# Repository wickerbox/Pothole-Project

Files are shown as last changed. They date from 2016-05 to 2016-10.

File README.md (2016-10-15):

# Pothole Project
Developing a low-cost device to collect and report real-time road information for cities. 

#### Step 1

Arduino 101 Shield using Fona, OBD-II/CAN circuitry, and an SD card. The board schematic was designed but not reviewed; the board was never laid out. 

Next step: lay out the board in KiCad and assemble a prototype

#### Step 2 

Standalone board using Fona, Curie chip, OBD-II/CAN circuitry, and an SD card. Ideally, it would fit into port so it could be left there to just do its thing.

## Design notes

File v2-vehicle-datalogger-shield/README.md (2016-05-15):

# Pothole Project
## Vehicle Datalogger Shield v1.0 

This shield is heavily based on the OBDII-UART adapter board from Sparkfun and ScanTool, but it adds headers for the Fona 808 2G + GPS breakout board and CC3000 Wifi breakout board, and provides an onboard miniSD holder for datalogging.  

### Bill of Materials

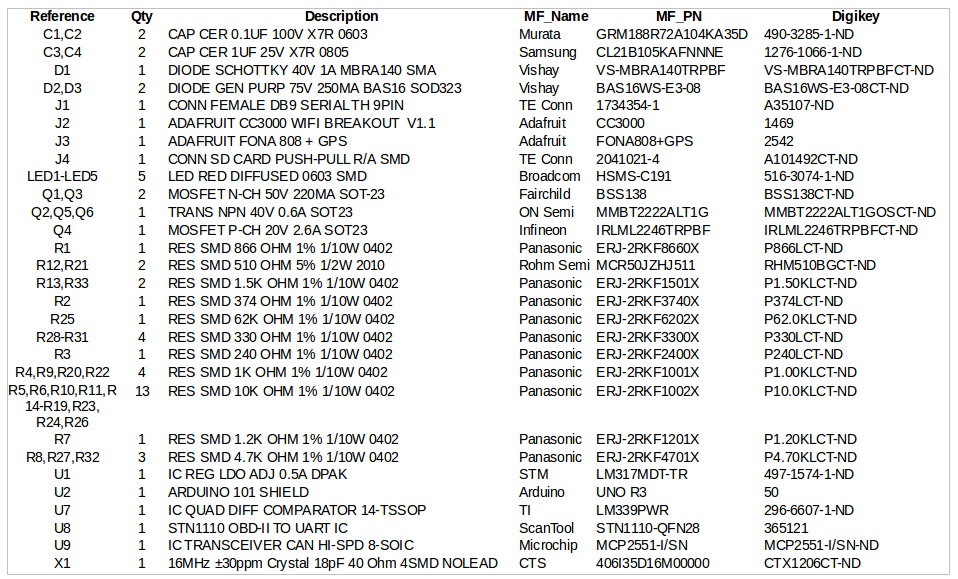
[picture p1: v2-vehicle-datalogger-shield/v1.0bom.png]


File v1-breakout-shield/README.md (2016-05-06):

# Pothole Project
## Hardware v1.0 

This is a simple breakout board to attach an OBDII-UART adapter board, Fona 808 2G + GPS breakout board, and an SD card to the Arduino 101. 

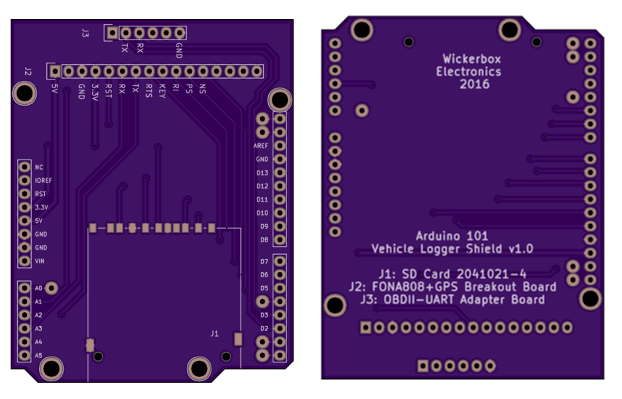
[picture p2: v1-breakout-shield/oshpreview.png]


### Bill of Materials

|Part|Source|Link|
|----|---|----|
|Arduino 101|Adafruit|<a href="https://www.adafruit.com/products/3033">$39.95</a>|
|Fona 808 2G + GPS Breakout Board|Adafruit|<a href="https://www.adafruit.com/products/2542">$49.95</a>|
|OBDII-UART Adapter Board|Sparkfun|<a href="https://www.sparkfun.com/products/9555">$49.95</a>
|SD Card holder|Digikey|<a href="http://www.digikey.com/product-search/en?keywords=A101492CT-ND">$3.10</a>|
|1x06 0.1" pitch female header|Digikey|<a href="http://www.digikey.com/product-search/en?keywords=952-1808-ND">$0.97</a>|
|1x16 0.1" pitch female header|Digikey|<a href="http://www.digikey.com/product-detail/en/sullins-connector-solutions/PPPC161LFBN-RC/S7049-ND/810188">$1.27</a>|

The printed board is a 2 layer board of 2.71x2.11 inches (69x53mm). $28.45 for three.

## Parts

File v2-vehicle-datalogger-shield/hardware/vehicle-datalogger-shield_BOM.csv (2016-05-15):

'Reference' | 'Qty' | 'Description' | 'MF_Name' | 'MF_PN' | 'Digikey'
'C1 | C2' | '2' | 'CAP CER 0.1UF 100V X7R 0603' | 'Murata' | 'GRM188R72A104KA35D' | '490-3285-1-ND'
'C3 | C4' | '2' | 'CAP CER 1UF 25V X7R 0805' | 'Samsung' | 'CL21B105KAFNNNE' | '1276-1066-1-ND'
'D1' | '1' | 'DIODE SCHOTTKY 40V 1A MBRA140 SMA' | 'Vishay' | 'VS-MBRA140TRPBF' | 'VS-MBRA140TRPBFCT-ND'
'D2 | D3' | '2' | 'DIODE GEN PURP 75V 250MA BAS16 SOD323' | 'Vishay' | 'BAS16WS-E3-08' | 'BAS16WS-E3-08CT-ND'
'J1' | '1' | 'CONN FEMALE DB9 SERIAL TH 9PIN' | 'TE Conn' | '1734354-1' | 'A35107-ND'
'J2' | '1' | 'ADAFRUIT CC3000 WIFI BREAKOUT V1.1' | 'Adafruit' | 'CC3000' | '1469'
'J3' | '1' | 'ADAFRUIT FONA 808 + GPS' | 'Adafruit' | 'FONA808+GPS' | '2542'
'J4' | '1' | 'CONN SD CARD PUSH-PULL R/A SMD' | 'TE Conn' | '2041021-4' | 'A101492CT-ND'
'LED1-LED5' | '5' | 'LED RED DIFFUSED 0603 SMD' | 'Broadcom' | 'HSMS-C191' | '516-3074-1-ND'
'Q1 | Q3' | '2' | 'MOSFET N-CH 50V 220MA SOT-23' | 'Fairchild' | 'BSS138' | 'BSS138CT-ND'
'Q2 | Q5 | Q6' | '1' | 'TRANS NPN 40V 0.6A SOT23' | 'ON Semi' | 'MMBT2222ALT1G' | 'MMBT2222ALT1GOSCT-ND'
'Q4' | '1' | 'MOSFET P-CH 20V 2.6A SOT23' | 'Infineon' | 'IRLML2246TRPBF' | 'IRLML2246TRPBFCT-ND'
'R1' | '1' | 'RES SMD 866 OHM 1% 1/10W 0402' | 'Panasonic' | 'ERJ-2RKF8660X' | 'P866LCT-ND'
'R12 | R21' | '2' | 'RES SMD 510 OHM 5% 1/2W 2010' | 'Rohm Semi' | 'MCR50JZHJ511' | 'RHM510BGCT-ND'
'R13 | R33' | '2' | 'RES SMD 1.5K OHM 1% 1/10W 0402' | 'Panasonic' | 'ERJ-2RKF1501X' | 'P1.50KLCT-ND'
'R2' | '1' | 'RES SMD 374 OHM 1% 1/10W 0402' | 'Panasonic' | 'ERJ-2RKF3740X' | 'P374LCT-ND'
'R25' | '1' | 'RES SMD 62K OHM 1% 1/10W 0402' | 'Panasonic' | 'ERJ-2RKF6202X' | 'P62.0KLCT-ND'
'R28-R31' | '4' | 'RES SMD 330 OHM 1% 1/10W 0402' | 'Panasonic' | 'ERJ-2RKF3300X' | 'P330LCT-ND'
'R3' | '1' | 'RES SMD 240 OHM 1% 1/10W 0402' | 'Panasonic' | 'ERJ-2RKF2400X' | 'P240LCT-ND'
'R4 | R9 | R20 | R22' | '4' | 'RES SMD 1K OHM 1% 1/10W 0402' | 'Panasonic' | 'ERJ-2RKF1001X' | 'P1.00KLCT-ND'
'R5 | R6 | R10 | R11 | R14-R19 | R23 | R24 | R26' | '13' | 'RES SMD 10K OHM 1% 1/10W 0402' | 'Panasonic' | 'ERJ-2RKF1002X' | 'P10.0KLCT-ND'
'R7' | '1' | 'RES SMD 1.2K OHM 1% 1/10W 0402' | 'Panasonic' | 'ERJ-2RKF1201X' | 'P1.20KLCT-ND'
'R8 | R27 | R32' | '3' | 'RES SMD 4.7K OHM 1% 1/10W 0402' | 'Panasonic' | 'ERJ-2RKF4701X' | 'P4.70KLCT-ND'
'U1' | '1' | 'IC REG LDO ADJ 0.5A DPAK' | 'STM' | 'LM317MDT-TR' | '497-1574-1-ND'
'U2' | '1' | 'ARDUINO 101 SHIELD' | 'Arduino' | 'UNO R3' | '50'
'U7' | '1' | 'IC QUAD DIFF COMPARATOR 14-TSSOP' | 'TI' | 'LM339PWR' | '296-6607-1-ND'
'U8' | '1' | 'STN1110 OBD-II TO UART IC' | 'ScanTool' | 'STN1110-QFN28' | '365121'
'U9' | '1' | 'IC TRANSCEIVER CAN HI-SPD 8-SOIC' | 'Microchip' | 'MCP2551-I/SN' | 'MCP2551-I/SN-ND'
'X1' | '1' | '16MHz ±30ppm Crystal 18pF 40 Ohm 4SMD NOLEAD' | 'CTS' | '406I35D16M00000' | 'CTX1206CT-ND'

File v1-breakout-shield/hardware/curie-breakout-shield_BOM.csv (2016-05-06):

Reference | Value | Footprint | Count | Datasheet | Package | MF_Name | MF_PN | S1_Name | S1_PN | Description | Verified
U1;U2;U3;U4 | HOLE | Wickerlib:ARDUINO-MOUNTING-HOLE | 4 | https://www.adafruit.com/products/50 | ARDU-101SHIELD | Arduino | 101 | Adafruit | 50 | ARDUINO 101 | Not Verified
U5 | ARDUINO-101-SHIELD | Wickerlib:ARDUINO-101-SHIELD | 1 | https://www.adafruit.com/products/3033 | ARDU-101SHIELD | Arduino | UNO R3 | Adafruit | 50 | ARDUINO 101 SHIELD | Not Verified
J1 | CONN-SD-CARD-PUSH-PULL-R/A-SMD | Wickerlib:SD_Holder_FullSize | 1 | http://www.te.com/commerce/DocumentDelivery/DDEController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 | SD_Holder_FullSize | TE Conn | 2041021-4 | Digikey | A101492CT-ND | CONN SD CARD PUSH-PULL R/A SMD | Not Verified
J2 | FONA808-GPS | Wickerlib:Pin_Header_Straight_1x16 | 1 | https://www.adafruit.com/products/2542 | FONA808-GPS | Adafruit | FONA808+GPS | Adafruit | 2542 | ADAFRUIT FONA 808 + GPS | Not Verified
J3 | OBDII-UART | Wickerlib:Pin_Header_Straight_1x06 | 1 | https://cdn.harwin.com/pdfs/60page140.pdf | Pin_Header_Straight_1x06 | Harwin | M20-7820642 | Digikey | 952-1808-ND | HEADER FEMALE 6POS TH 1x06 0.1” | Not Verified
W2 | A0 | Wickerlib:TestHole_1x01 | 1
W4 | A4 | Wickerlib:TestHole_1x01 | 1
W6 | A5 | Wickerlib:TestHole_1x01 | 1
W1 | D0 | Wickerlib:TestHole_1x01 | 1
W3 | D1 | Wickerlib:TestHole_1x01 | 1
W5 | D4 | Wickerlib:TestHole_1x01 | 1

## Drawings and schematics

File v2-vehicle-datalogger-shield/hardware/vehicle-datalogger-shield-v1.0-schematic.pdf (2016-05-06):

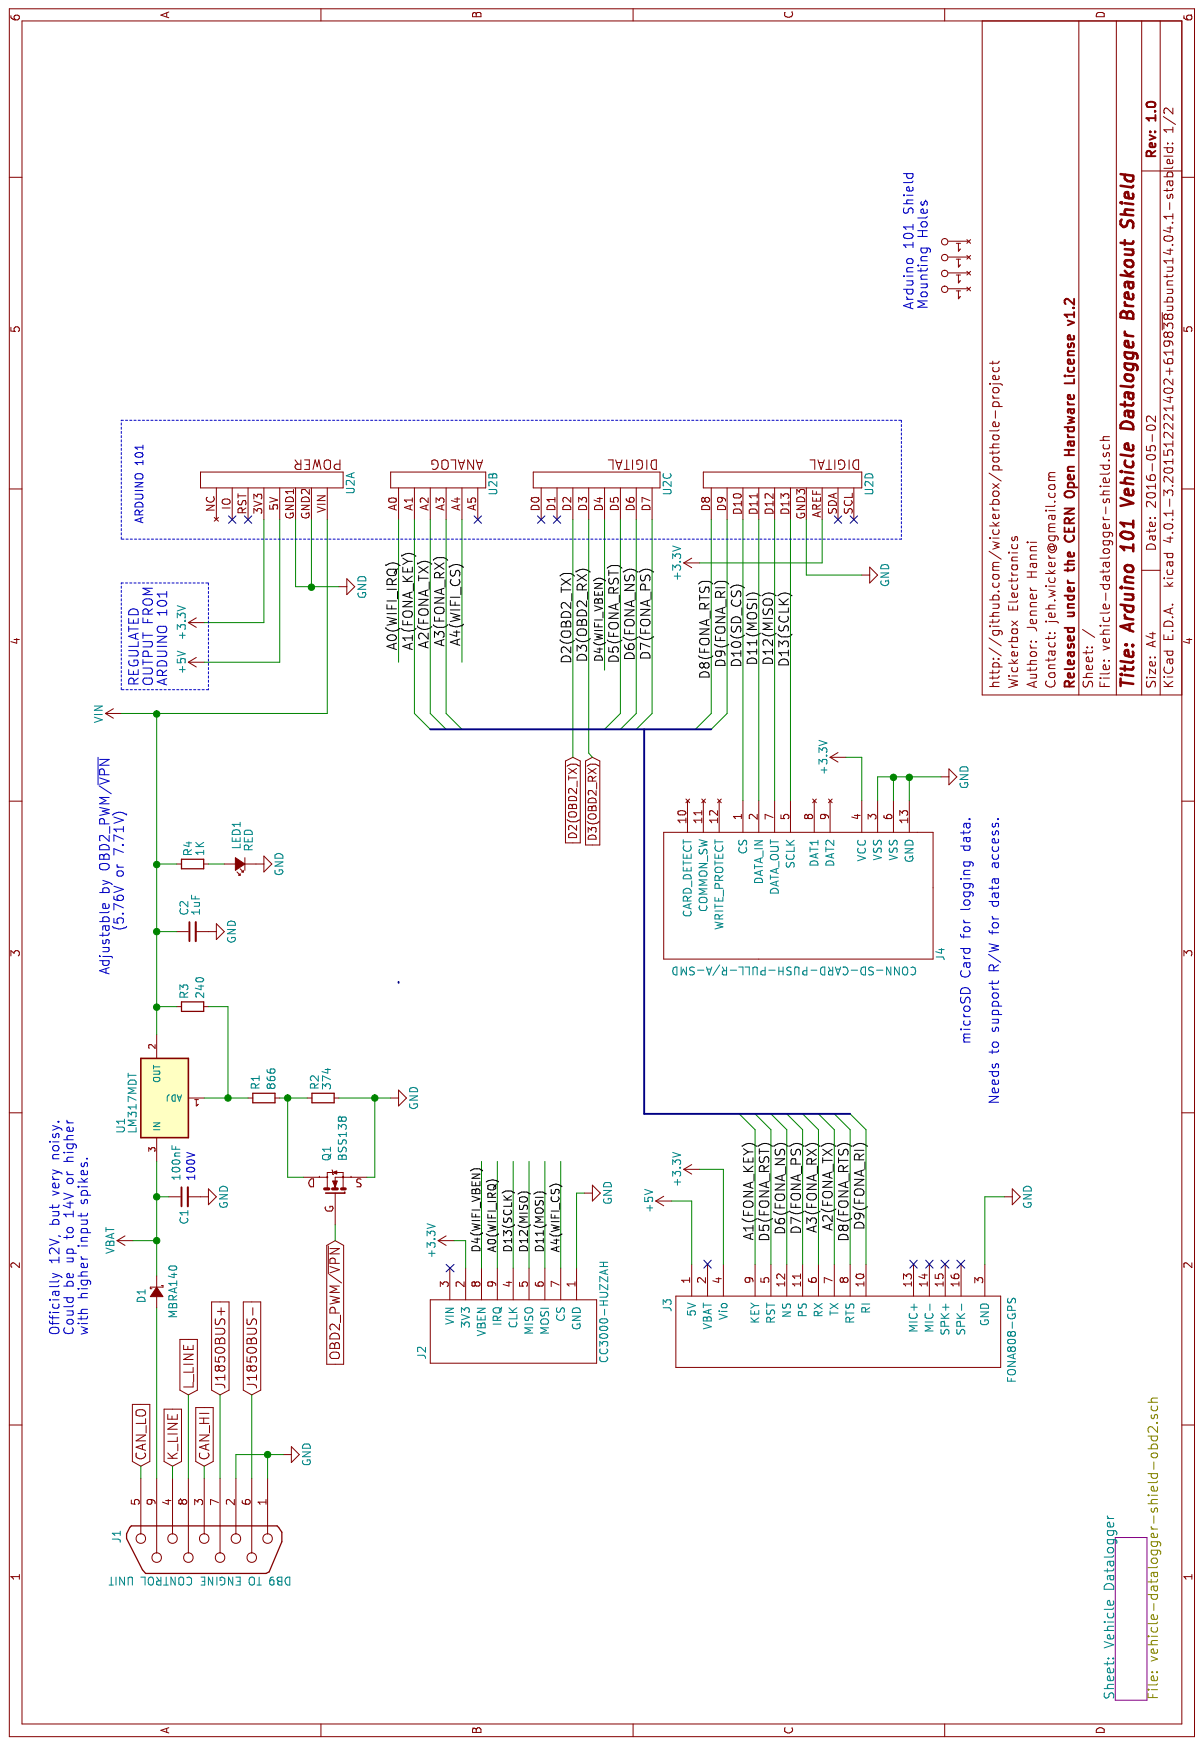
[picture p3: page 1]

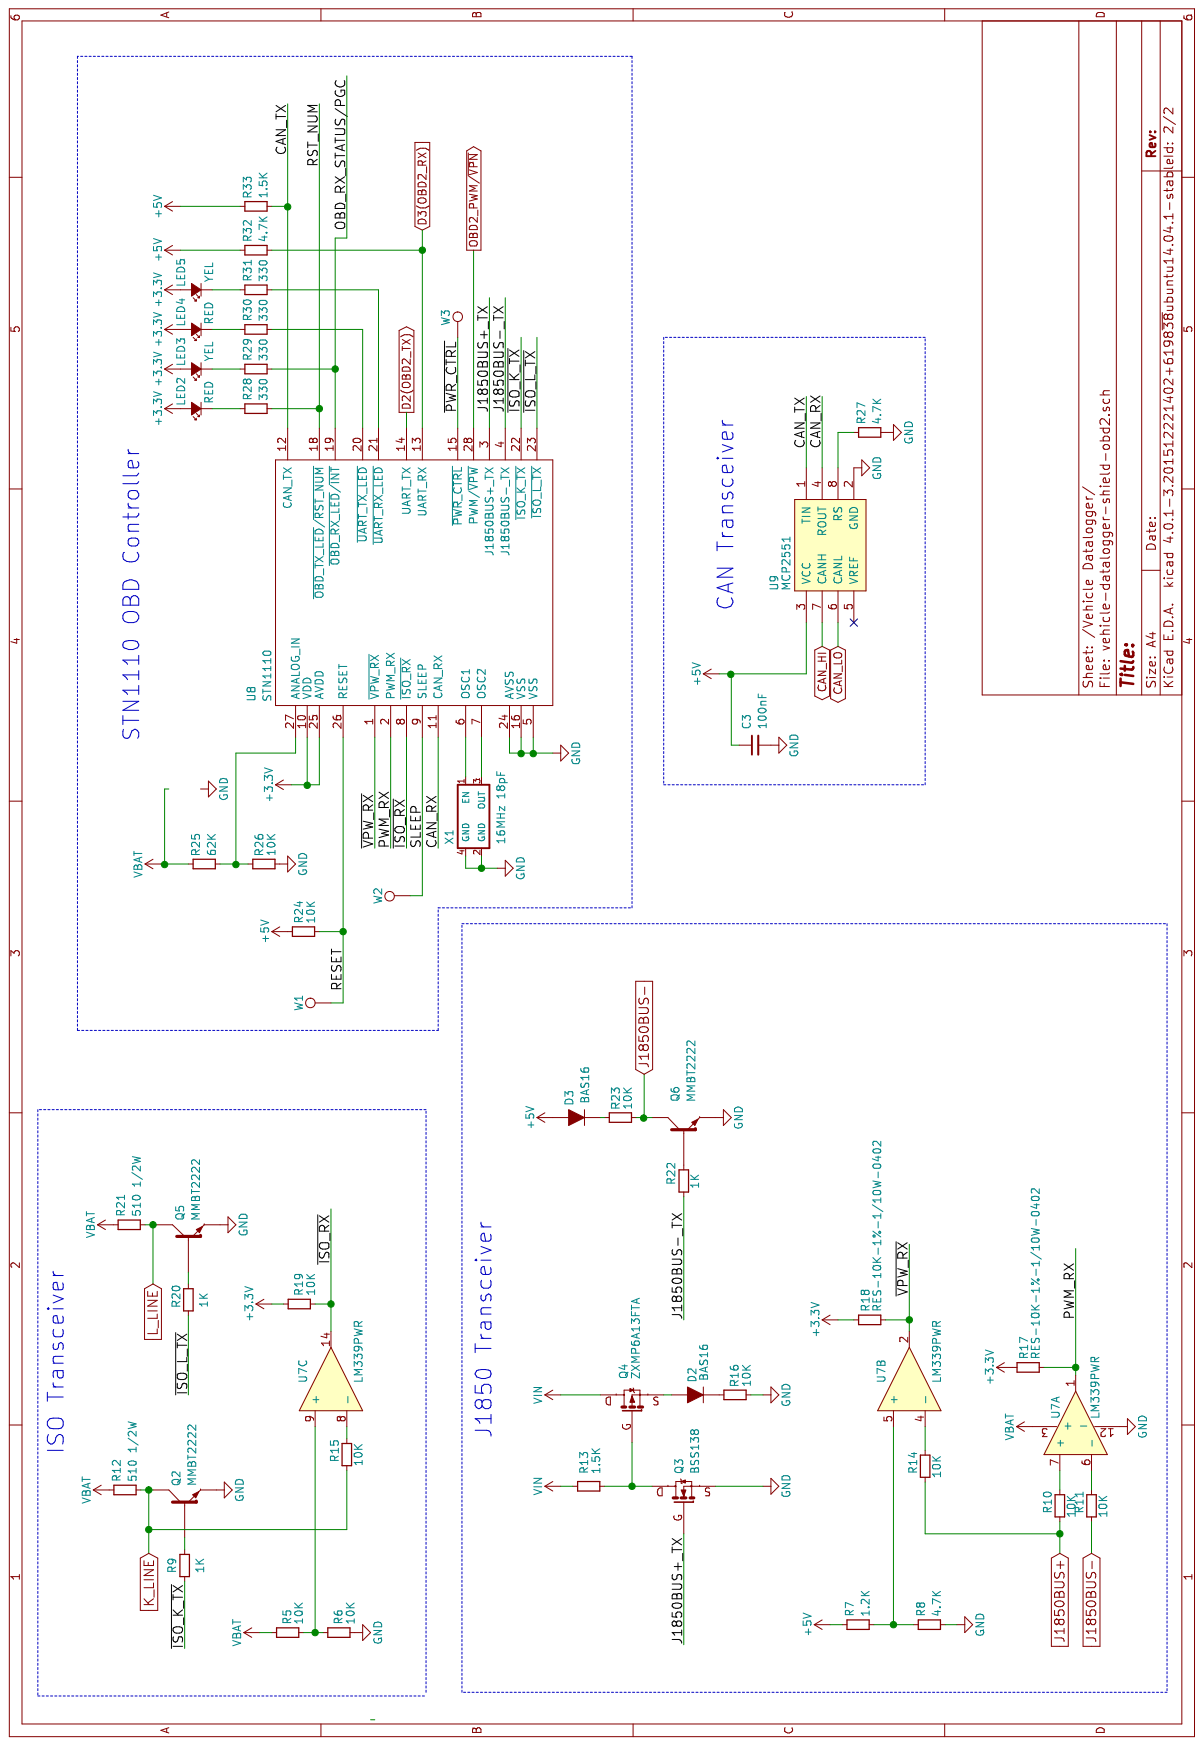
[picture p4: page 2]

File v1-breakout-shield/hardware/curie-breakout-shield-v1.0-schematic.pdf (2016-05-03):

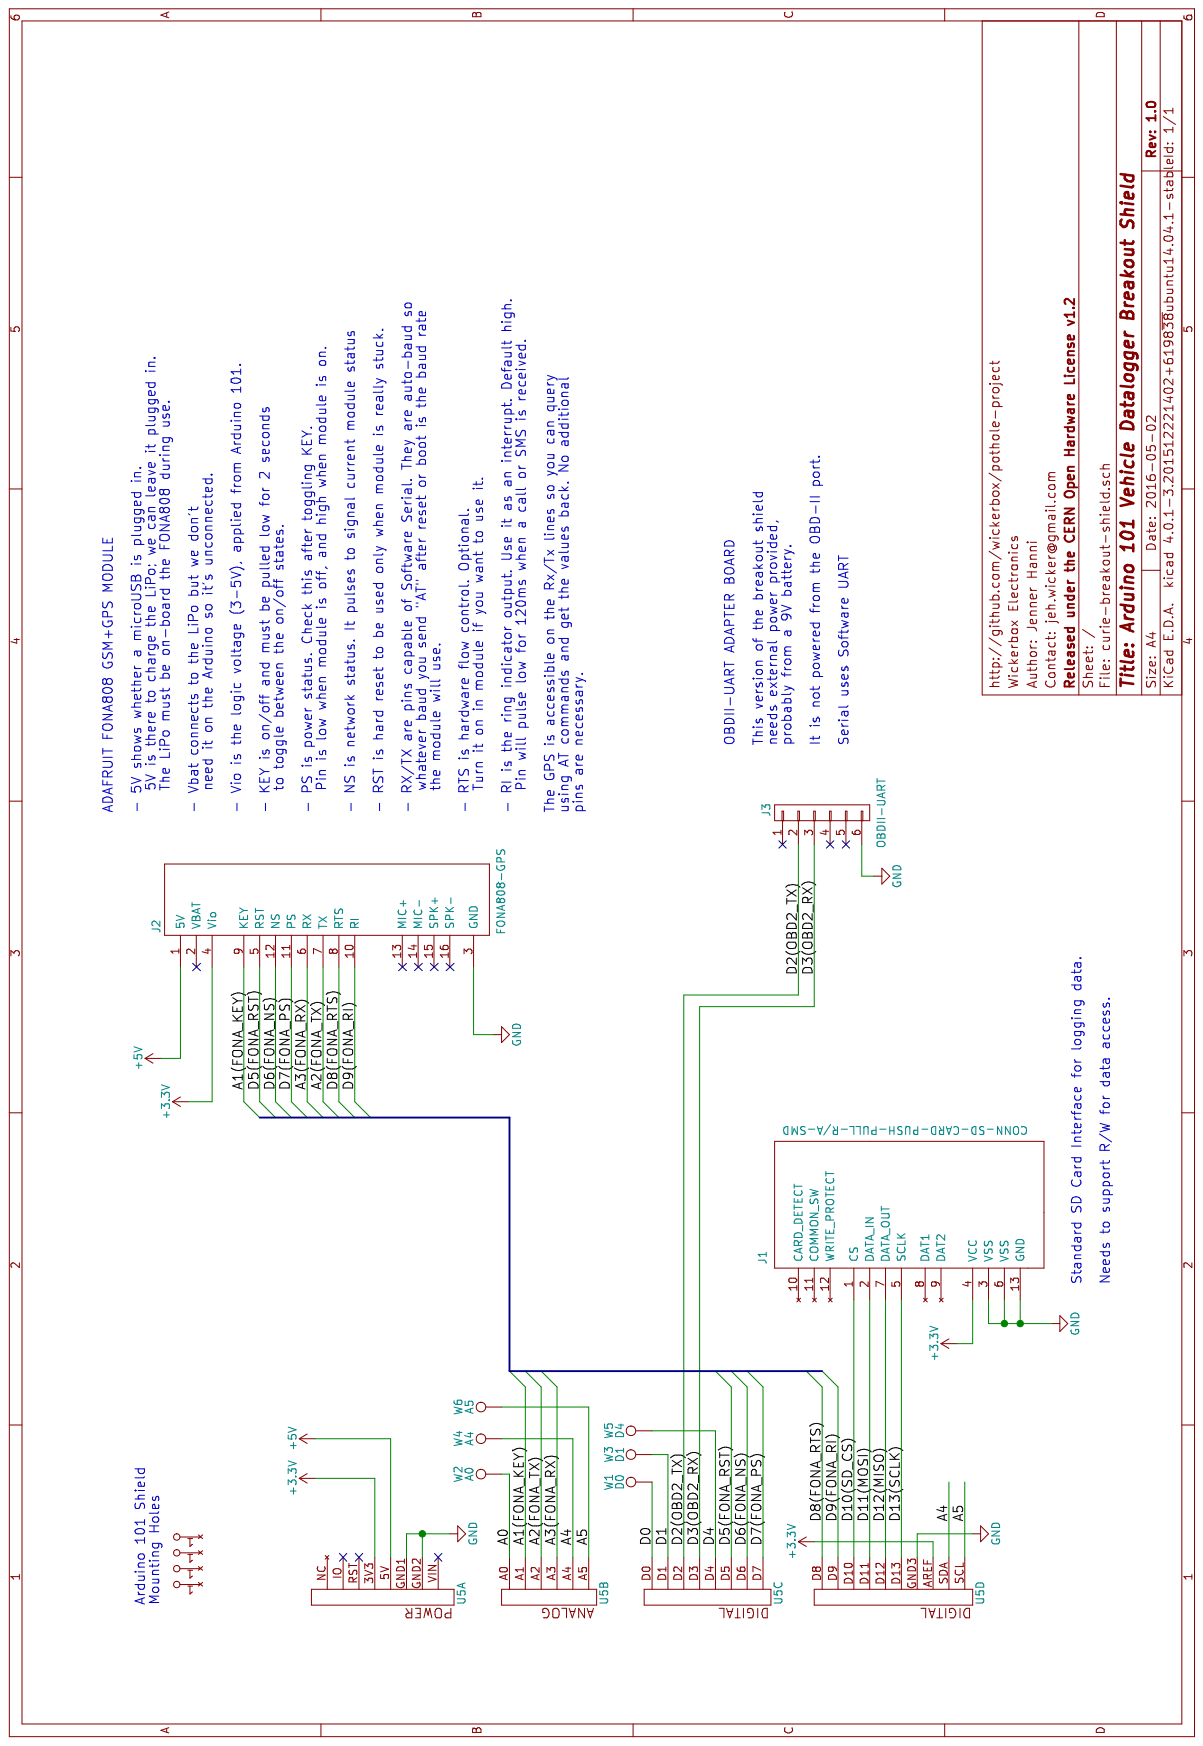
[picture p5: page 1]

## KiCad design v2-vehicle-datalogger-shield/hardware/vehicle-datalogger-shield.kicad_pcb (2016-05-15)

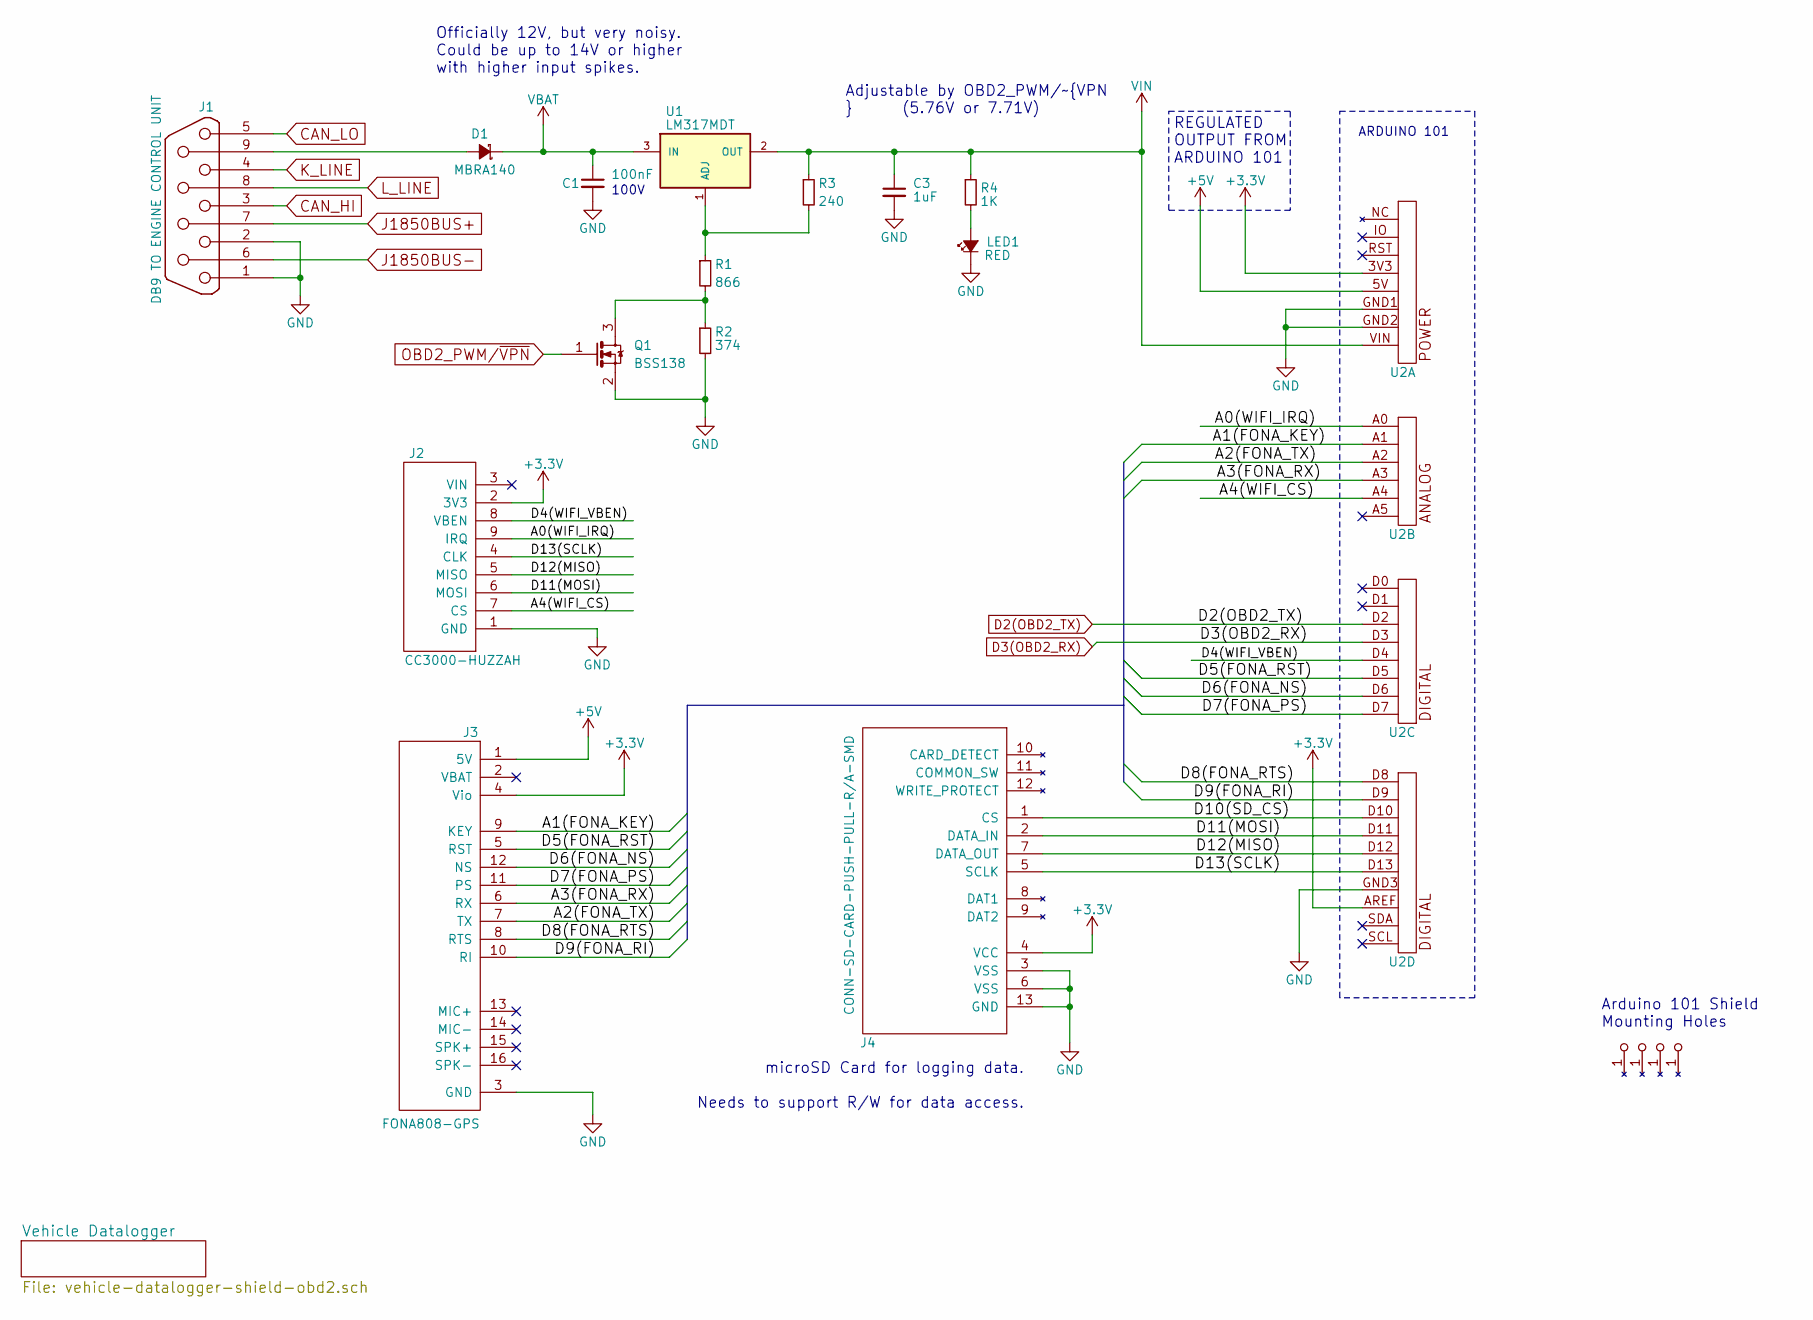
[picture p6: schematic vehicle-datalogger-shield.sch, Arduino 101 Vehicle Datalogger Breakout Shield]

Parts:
C1: 100nF; 0603
C3: 1uF; 0805
D1: MBRA140; Diode_SMA
J1: DB9 TO ENGINE CONTROL UNIT; DB9FC
J2: CC3000-HUZZAH; CC3000BKOUT
J3: FONA808-GPS; Pin_Header_Straight_1x16
J4: CONN-SD-CARD-PUSH-PULL-R/A-SMD; SD_Holder_FullSize
LED1: RED; 0603
Q1: BSS138; SOT-23-3
R1: 866; 0402
R2: 374; 0402
R3: 240; 0402
R4: 1K; 0402
U1: LM317MDT; DPAK
U2: ARDUINO-101-SHIELD
U3, U4, U5, U6: HOLE; ARDUINO-MOUNTING-HOLE

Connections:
+3V3: J2.2 (3V3), J3.4 (Vio), J4.4 (VCC), U2.3V3 (3.3V), U2.AREF; also elsewhere on the board
+5V: J3.1 (5V), U2.5V; also elsewhere on the board
/A0(WIFI_IRQ): J2.9 (IRQ), U2.A0
/A1(FONA_KEY): J3.9 (KEY), U2.A1
/A2(FONA_TX): J3.7 (TX), U2.A2
/A3(FONA_RX): J3.6 (RX), U2.A3
/A4(WIFI_CS): J2.7 (CS), U2.A4
/D4(WIFI_VBEN): J2.8 (VBEN), U2.D4
/D5(FONA_RST): J3.5 (RST), U2.D5
/D6(FONA_NS): J3.12 (NS), U2.D6
/D7(FONA_PS): J3.11 (PS), U2.D7
/D8(FONA_RTS): J3.8 (RTS), U2.D8
/D9(FONA_RI): J3.10 (RI), U2.D9
/D10(SD_CS): J4.1 (CS), U2.D10
/D11(MOSI): J2.6 (MOSI), J4.2 (DATA_IN), U2.D11
/D12(MISO): J2.5 (MISO), J4.7 (DATA_OUT), U2.D12
/D13(SCLK): J2.4 (CLK), J4.5 (SCLK), U2.D13
CAN_HI: J1.3; also elsewhere on the board
CAN_LO: J1.5; also elsewhere on the board
D2(OBD2_TX): U2.D2; also elsewhere on the board
D3(OBD2_RX): U2.D3; also elsewhere on the board
GND: C1.2, C3.2, J1.1, J1.2, J2.1 (GND), J3.3 (GND), J4.3 (VSS), J4.6 (VSS), J4.13 (GND), LED1.1 (K), Q1.2 (S), R2.2, U2.GND1 (GND), U2.GND2 (GND), U2.GND3 (GND); also elsewhere on the board
J1850BUS+: J1.7; also elsewhere on the board
J1850BUS-: J1.6; also elsewhere on the board
K_LINE: J1.4; also elsewhere on the board
L_LINE: J1.8; also elsewhere on the board
unnamed: D1.2 (A), J1.9
unnamed: LED1.2 (A), R4.2
unnamed: Q1.3 (D), R1.2, R2.1
unnamed: R1.1, R3.2, U1.1 (ADJ)
OBD2_PWM/~VPN: Q1.1 (G); also elsewhere on the board
VBAT: C1.1, D1.1 (K), U1.3 (IN); also elsewhere on the board
VIN: C3.1, R3.1, R4.1, U1.2 (OUT), U2.VIN; also elsewhere on the board

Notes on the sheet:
Arduino 101 Shield Mounting Holes
microSD Card for logging data. Needs to support R/W for data access.
Officially 12V, but very noisy. Could be up to 14V or higher with higher input spikes.
REGULATED OUTPUT FROM ARDUINO 101
100V
Adjustable by OBD2_PWM/~VPN (5.76V or 7.71V)
ARDUINO 101

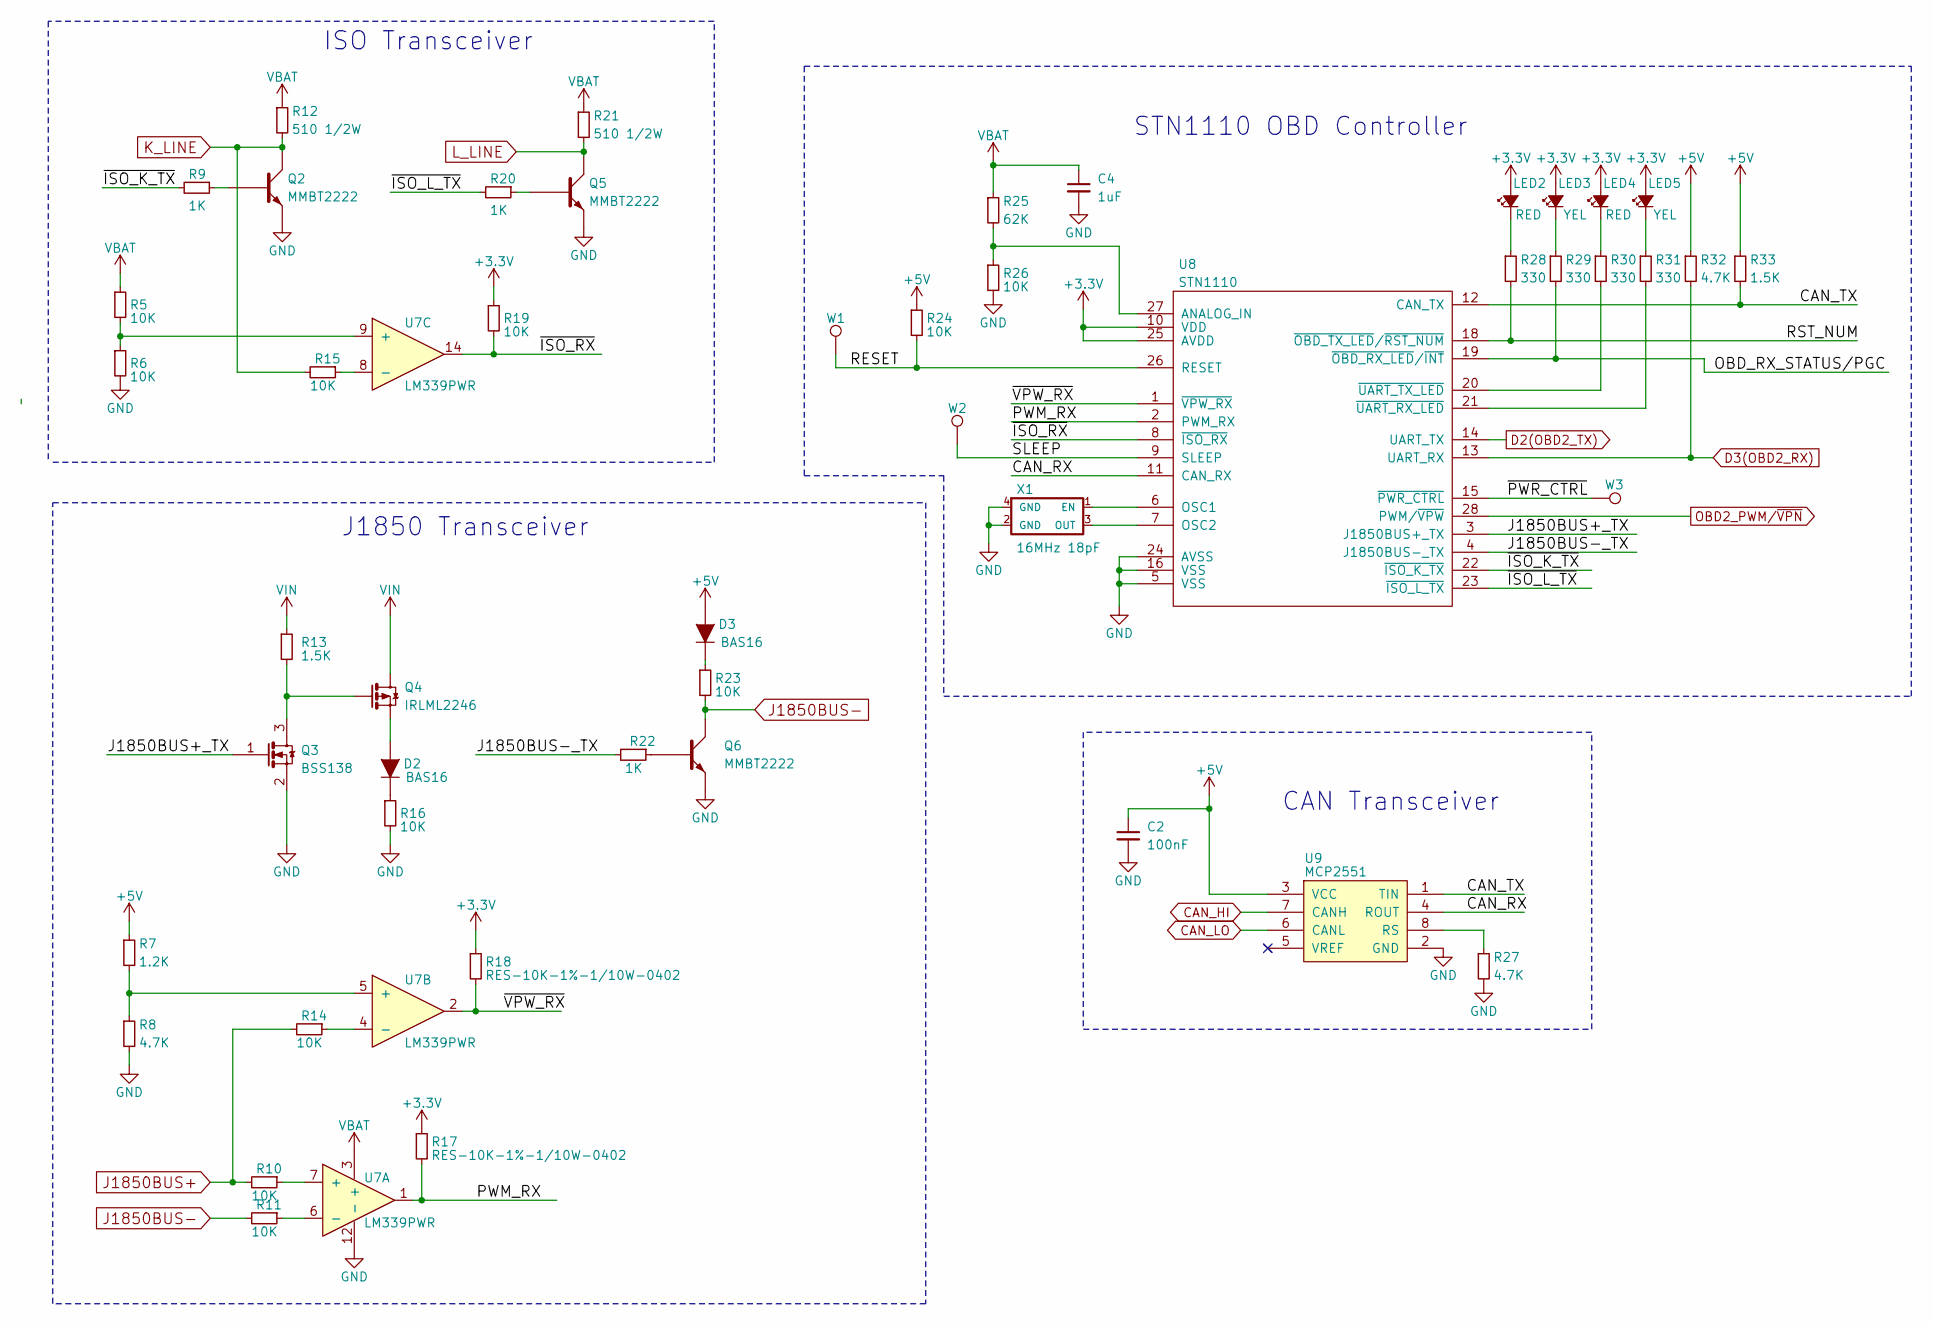
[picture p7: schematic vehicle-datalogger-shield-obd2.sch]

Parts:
C2: 100nF; 0603
C4: 1uF; 0805
D2, D3: BAS16; SOD-323
LED2, LED4: RED; 0603
LED3, LED5: YEL; 0603
Q2, Q5, Q6: MMBT2222; SOT-23-3
Q3: BSS138; SOT-23-3
Q4: IRLML2246; SOT-23-3
R5, R6, R10, R11, R14, R15, R16, R19, R23, R24, R26: 10K; 0402
R7: 1.2K; 0402
R8, R27, R32: 4.7K; 0402
R9, R20, R22: 1K; 0402
R12, R21: 510 1/2W; 2010
R13, R33: 1.5K; 0402
R17, R18: RES-10K-1%-1/10W-0402; 0402
R25: 62K; 0402
R28, R29, R30, R31: 330; 0402
U7: LM339PWR; TSSOP-14_4.4x5mm_Pitch0.65mm
U8: STN1110; QFN-32-1EP_5x5mm_Pitch0.5mm
U9: MCP2551; SOIC-8_3.9x4.9mm_Pitch1.27mm
W1, W2, W3: TEST_1P; Pin_Header_Straight_1x01
X1: 16MHz 18pF; CRYSTAL-CTS-4SMD

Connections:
+3V3: LED2.2 (A), LED3.2 (A), LED4.2 (A), LED5.2 (A), R17.1, R18.1, R19.1, U8.10 (VDD), U8.25 (AVDD); also elsewhere on the board
+5V: C2.1, D3.2 (A), R7.1, R24.1, R32.1, R33.1, U9.3 (VCC); also elsewhere on the board
/Vehicle Datalogger/CAN_RX: U8.11 (CAN_RX), U9.4 (ROUT)
/Vehicle Datalogger/CAN_TX: R33.2, U8.12 (CAN_TX), U9.1 (TIN)
/Vehicle Datalogger/J1850BUS+_TX: Q3.1 (G), U8.3 (J1850BUS+_TX)
/Vehicle Datalogger/J1850BUS-_TX: R22.2, U8.4 (J1850BUS-_TX)
/Vehicle Datalogger/OBD_RX_STATUS/PGC: R29.2, U8.19 (~OBD_RX_LED~/~INT)
/Vehicle Datalogger/PWM_RX: R17.2, U7.1, U8.2 (PWM_RX)
/Vehicle Datalogger/RESET: R24.2, U8.26 (RESET), W1.1
/Vehicle Datalogger/RST_NUM: R28.2, U8.18 (~OBD_TX_LED~/~RST_NUM)
/Vehicle Datalogger/SLEEP: U8.9 (SLEEP), W2.1
/Vehicle Datalogger/~ISO_K_TX: R9.2, U8.22 (~ISO_K_TX)
/Vehicle Datalogger/~ISO_L_TX: R20.2, U8.23 (~ISO_L_TX)
/Vehicle Datalogger/~ISO_RX: R19.2, U7.14, U8.8 (~ISO_RX)
/Vehicle Datalogger/~PWR_CTRL: U8.15 (~PWR_CTRL), W3.1
/Vehicle Datalogger/~VPW_RX: R18.2, U7.2, U8.1 (~VPW_RX)
CAN_HI: U9.7 (CANH); also elsewhere on the board
CAN_LO: U9.6 (CANL); also elsewhere on the board
D2(OBD2_TX): U8.14 (UART_TX); also elsewhere on the board
D3(OBD2_RX): R32.2, U8.13 (UART_RX); also elsewhere on the board
GND: C2.2, C4.2, Q2.2 (E), Q3.2 (S), Q5.2 (E), Q6.2 (E), R6.2, R8.2, R16.2, R26.2, R27.2, U7.12 (-), U8.5 (VSS), U8.16 (VSS), U8.24 (AVSS), U9.2 (GND), X1.2 (GND), X1.4 (GND); also elsewhere on the board
J1850BUS+: R10.2, R14.2; also elsewhere on the board
J1850BUS-: Q6.3 (C), R11.2, R23.2; also elsewhere on the board
K_LINE: Q2.3 (C), R12.2, R15.2; also elsewhere on the board
L_LINE: Q5.3 (C), R21.2; also elsewhere on the board
unnamed: D2.1 (K), R16.1
unnamed: D2.2 (A), Q4.2 (S)
unnamed: D3.1 (K), R23.1
unnamed: LED2.1 (K), R28.1
unnamed: LED3.1 (K), R29.1
unnamed: LED4.1 (K), R30.1
unnamed: LED5.1 (K), R31.1
unnamed: Q2.1 (B), R9.1
unnamed: Q3.3 (D), Q4.1 (G), R13.2
unnamed: Q5.1 (B), R20.1
unnamed: Q6.1 (B), R22.1
unnamed: R5.2, R6.1, U7.9 (+)
unnamed: R7.2, R8.1, U7.5 (+)
unnamed: R10.1, U7.7 (+)
unnamed: R11.1, U7.6 (-)
unnamed: R14.1, U7.4 (-)
unnamed: R15.1, U7.8 (-)
unnamed: R25.2, R26.1, U8.27 (ANALOG_IN)
unnamed: R27.1, U9.8 (RS)
unnamed: R30.2, U8.20 (~UART_TX_LED)
unnamed: R31.2, U8.21 (~UART_RX_LED)
unnamed: U8.6 (OSC1), X1.1 (EN)
unnamed: U8.7 (OSC2), X1.3 (OUT)
OBD2_PWM/~VPN: U8.28 (PWM/~VPW); also elsewhere on the board
VBAT: C4.1, R5.1, R12.1, R21.1, R25.1, U7.3 (+); also elsewhere on the board
VIN: Q4.3 (D), R13.1; also elsewhere on the board

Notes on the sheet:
J1850 Transceiver
ISO Transceiver
CAN Transceiver
STN1110 OBD Controller

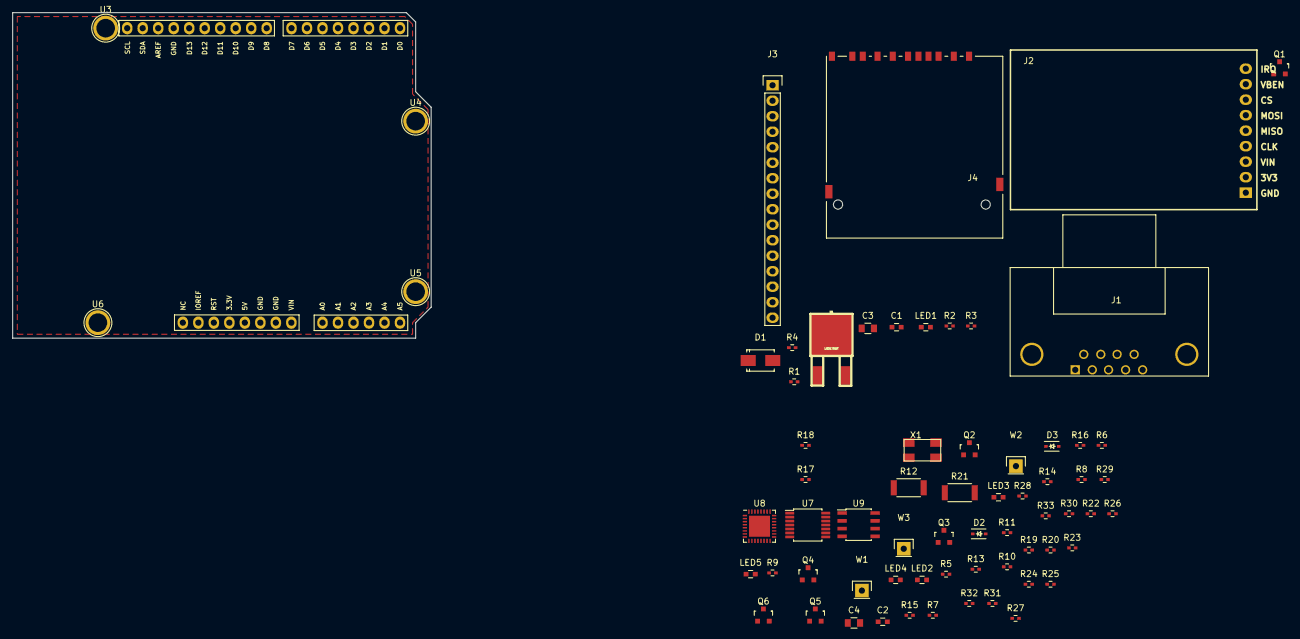
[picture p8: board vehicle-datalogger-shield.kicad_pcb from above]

Board: 2 copper layers, 68.6 x 53.3 mm, 68 parts (0 on the bottom side), 70 nets.

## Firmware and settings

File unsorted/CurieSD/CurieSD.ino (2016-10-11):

#include <SPI.h>
#include <SD.h>
#include <CurieIMU.h>

// -----------------------------------
// pin assignments

uint8_t redPin = 5;
uint8_t greenPin = 6;
uint8_t sdPin_CS = 10;
uint8_t sdPin_MISO = 11;
uint8_t sdPin_MOSI = 12;
uint8_t sdPin_SCLK = 13;

// -----------------------------------
// sd card globals

Sd2Card card;
SdVolume volume;
SdFile root;

File logfile;
File myFile;

char logfileName[] = "logging.txt";
char chars[32];
char inChar = 'x';
uint8_t numChar = 0;
uint8_t charidx = 0;

// -----------------------------------
// accelerometer globals

int axRaw, ayRaw, azRaw;
float ax, ay, az;

// -----------------------------------
// gyro globals

int gxRaw, gyRaw, gzRaw;         // raw gyro values
float gx, gy, gz;

// -----------------------------------
// set globals

void setLEDs(uint8_t redLevel, uint8_t greenLevel) {
  digitalWrite(redPin, redLevel);
  digitalWrite(greenPin, greenLevel);
}

// -----------------------------------
// add a character to the string for the sd card

void addCharToString(char newChar) {
  chars[numChar] = newChar;
  numChar += 1;
}

// -----------------------------------
// make a single read from the accelerometer
// and convert raw data to G's

void readCurieAccel() {
  CurieIMU.readAccelerometer(axRaw, ayRaw, azRaw);
  ax = convertRawAcceleration(axRaw);
  ay = convertRawAcceleration(ayRaw);
  az = convertRawAcceleration(azRaw);
}

// -----------------------------------
// make a single read from the gyro

void readCurieGyro() {
  CurieIMU.readGyro(gxRaw, gyRaw, gzRaw);
  gx = convertRawGyro(gxRaw);
  gy = convertRawGyro(gyRaw);
  gz = convertRawGyro(gzRaw);
}

// -----------------------------------
// convert raw data to g's
//   since we are using 2G range
//   -2g maps to a raw value of -32768
//   +2g maps to a raw value of 32767

float convertRawAcceleration(int aRaw) {
  float a = (aRaw * 2.0) / 32768.0;
  return a;
}

// -----------------------------------
// convert raw data to degrees per second
//   since we are using 250 degrees/seconds range
//   -250 maps to a raw value of -32768
//   +250 maps to a raw value of 32767

float convertRawGyro(int gRaw) {
  float g = (gRaw * 250.0) / 32768.0;
  return g;
}

// -----------------------------------
// main setup for the program

void setup() {
  // put your setup code here, to run once:
  Serial.begin(9600);
  delay(2000);

  Serial.println("Setting up the program.");
  pinMode(redPin, OUTPUT);
  pinMode(greenPin, OUTPUT);

  // init SD card and create file if it does not already exist
  if (!SD.begin(sdPin_CS)) {
    setLEDs(HIGH, LOW);
    Serial.println("Setup of SD card failed. No logging will take place.");
    while (1) {};
  }

  myFile = SD.open(logfileName, FILE_WRITE);
  myFile.close();

  CurieIMU.begin();
  CurieIMU.setAccelerometerRange(2);  // 2g
  CurieIMU.setGyroRange(250);         // deg/sec

  Serial.println("Setup complete.");
  return;
}

// -----------------------------------
// main setup for the program
//
// accepts the following chars over serial
// 'r' (red)
// 'g' (green)
// 'b' (both)
// 'n' (none)
// 'w' (write to SD card)
// 'i' (read from SD card)
// 'a' (read from accelerometer, print to screen only)
// 'y' (read from gyro, print to screen only)

void loop() {

  if (numChar > 30) {
    Serial.print("Write these chars: ");
    Serial.println(chars);
    logfile = SD.open("logging.txt", FILE_WRITE);
    if (logfile) {
      logfile.println(chars);
      logfile.close();
    }
    else {
      Serial.println("Logfile does not exist. Write failed.");
    }
    numChar = 0;
  }

  if (Serial.available() > 0) {
    inChar = Serial.read();
    Serial.println(inChar, DEC);

    // only red led on
    if (inChar == 114) {
      setLEDs(HIGH, LOW);
      addCharToString(inChar);
    }

    // only green led on
    else if (inChar == 103) {
      setLEDs(LOW, HIGH);
      addCharToString(inChar);
    }

    // turn both leds on
    else if (inChar == 110) {
      setLEDs(LOW, LOW);
      addCharToString(inChar);
    }

    // turn off both leds
    else if (inChar == 98) {
      setLEDs(HIGH, HIGH);
      addCharToString(inChar);
    }

    // write to the SD card
    else if (inChar == 119) {
      Serial.print("Write these chars: ");
      logfile = SD.open("logging.txt", FILE_WRITE);
      if (logfile) {
        for (charidx = 0; charidx < numChar; charidx++) {
          logfile.print(chars[charidx]);
          Serial.print(chars[charidx]);
        }
        logfile.print('n');
        logfile.close();
      }
      else {
        Serial.println("Logfile does not exist. Write failed.");
      }
      numChar = 0;
    }

    // read sd card
    else if (inChar == 105) {
      logfile = SD.open("logging.txt", FILE_READ);
      if (logfile) {
        while (logfile.available()) {
          Serial.write(logfile.read());
        }
        logfile.close();
      }
    }

    // read accelerometer
    else if (inChar == 97) {
      readCurieAccel();
      Serial.print("a:\t");
      Serial.print(ax);
      Serial.print("\t");
      Serial.print(ay);
      Serial.print("\t");
      Serial.print(az);
      Serial.println();
    }

    // read gyro
    else if (inChar == 121) {
      readCurieGyro();
      Serial.print("g:\t");
      Serial.print(gx);
      Serial.print("\t");
      Serial.print(gy);
      Serial.print("\t");
      Serial.print(gz);
      Serial.println();
    }
    delay(500);
  }

}

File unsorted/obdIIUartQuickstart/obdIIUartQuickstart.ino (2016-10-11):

/*
* OBD-II-UART Quickstart Sketch
* Written by Ryan Owens for SparkFun Electronics 7/5/2011
* Updates for Arduino 1.0+ by Toni Klopfenstein
*
* Released under the 'beerware' license
* (Do what you want with the code, but if we ever meet then you buy me a beer)
*
* This sketch will grab RPM and Vehicle Speed data from a vehicle with an OBD port
* using the OBD-II-UART board from SparkFun electronics. The data will be displayed
* on a serial 16x2 LCD. See the tutorial at https://www.sparkfun.com/tutorials/294
* to learn how to hook up the hardware:
*
*/

#include <SoftwareSerial.h>

//Create an instance of the new soft serial library to control the serial LCD
//Note, digital pin 3 of the Arduino should be connected to Rx of the serial LCD.

SoftwareSerial lcd(2,3);

//This is a character buffer that will store the data from the serial port
char rxData[20];
char rxIndex=0;

//Variables to hold the speed and RPM data.
int vehicleSpeed=0;
int vehicleRPM=0;

void setup(){
  //Both the Serial LCD and the OBD-II-UART use 9600 bps.
  lcd.begin(9600);
  Serial.begin(9600);
  
  //Clear the old data from the LCD.
  lcd.write(254);
  lcd.write(1);  
  
  //Put the speed header on the first row.
  lcd.print("Speed: ");
  lcd.write(254);
  //Put the RPM header on the second row.
  lcd.write(128+64);
  lcd.print("RPM: ");
  
  //Wait for a little while before sending the reset command to the OBD-II-UART
  delay(1500);
  //Reset the OBD-II-UART
  Serial.println("ATZ");
  //Wait for a bit before starting to send commands after the reset.
  delay(2000);
  
  //Delete any data that may be in the serial port before we begin.
  Serial.flush();
}

void loop(){
  //Delete any data that may be in the serial port before we begin.  
  Serial.flush();
  //Set the cursor in the position where we want the speed data.
  lcd.write(254);
  lcd.write(128+8);
  //Clear out the old speed data, and reset the cursor position.
  lcd.print("        ");
  lcd.write(254);
  lcd.write(128+8);
  //Query the OBD-II-UART for the Vehicle Speed
  Serial.println("010D");
  //Get the response from the OBD-II-UART board. We get two responses
  //because the OBD-II-UART echoes the command that is sent.
  //We want the data in the second response.
  getResponse();
  getResponse();
  //Convert the string data to an integer
  vehicleSpeed = strtol(&rxData[6],0,16);
  //Print the speed data to the lcd
  lcd.print(vehicleSpeed);
  lcd.print(" km/h");
  delay(100);
  
  //Delete any data that may be left over in the serial port.
  Serial.flush();
  //Move the serial cursor to the position where we want the RPM data.
  lcd.write(254);
  lcd.write(128 + 69);
  //Clear the old RPM data, and then move the cursor position back.
  lcd.print("          ");
  lcd.write(254);
  lcd.write(128+69);

  //Query the OBD-II-UART for the Vehicle rpm
  Serial.println("010C");
  //Get the response from the OBD-II-UART board
  getResponse();
  getResponse();
  //Convert the string data to an integer
  //NOTE: RPM data is two bytes long, and delivered in 1/4 RPM from the OBD-II-UART
  vehicleRPM = ((strtol(&rxData[6],0,16)*256)+strtol(&rxData[9],0,16))/4;
  //Print the rpm data to the lcd
  lcd.print(vehicleRPM); 
  
  //Give the OBD bus a rest
  delay(100);
  
}

//The getResponse function collects incoming data from the UART into the rxData buffer
// and only exits when a carriage return character is seen. Once the carriage return
// string is detected, the rxData buffer is null terminated (so we can treat it as a string)
// and the rxData index is reset to 0 so that the next string can be copied.
void getResponse(void){
  char inChar=0;
  //Keep reading characters until we get a carriage return
  while(inChar != '\r'){
    //If a character comes in on the serial port, we need to act on it.
    if(Serial.available() > 0){
      //Start by checking if we've received the end of message character ('\r').
      if(Serial.peek() == '\r'){
        //Clear the Serial buffer
        inChar=Serial.read();
        //Put the end of string character on our data string
        rxData[rxIndex]='\0';
        //Reset the buffer index so that the next character goes back at the beginning of the string.
        rxIndex=0;
      }
      //If we didn't get the end of message character, just add the new character to the string.
      else{
        //Get the new character from the Serial port.
        inChar = Serial.read();
        //Add the new character to the string, and increment the index variable.
        rxData[rxIndex++]=inChar;
      }
    }
  }
}

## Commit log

2016-05-03 Added schematic for very first breakout board shield, because protoboards suck.
    [curie-breakout-shield.kicad_pcb, curie-breakout-shield.sch]
2016-05-03 Ordered the breakout board v1.0 from OSH Park.
    [curie-breakout-shield-B.Cu.gbl, curie-breakout-shield-B.Mask.gbs, curie-breakout-shield-B.Paste.gbp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]
2016-05-03 Starting the vehicle datalogger shield with everything on board.
    [vehicle-datalogger-shield.kicad_pcb, vehicle-datalogger-shield.sch]
2016-05-04 Nearly done. Just need to add CC3000 and verify connections.
    [vehicle-datalogger-shield-obd2.sch, vehicle-datalogger-shield.sch]
2016-05-04 Added CC3000 and fixed all other packages. Ready for check.
    [vehicle-datalogger-shield-obd2.sch, vehicle-datalogger-shield.sch]
2016-05-06 Added generated BOM and README.
    [curie-breakout-shield_BOM.csv]
2016-05-06 Pothole vehicle datalogger shield v1.0 schematic is done.
    [vehicle-datalogger-shield-obd2.sch, vehicle-datalogger-shield.sch, vehicle-datalogger-shield_BOM.csv]
2016-05-10 Added missing footprints, finished symbol-footprint association.
    [vehicle-datalogger-shield-obd2.sch, vehicle-datalogger-shield.sch]
2016-05-15 Updated schematic, BOM, and spread out footprints. Ready to layout.
    [vehicle-datalogger-shield-obd2.sch, vehicle-datalogger-shield.kicad_pcb, vehicle-datalogger-shield.sch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]
2016-05-15 New pic of BOM.
2016-05-15 Hopefully added new BOM picture.

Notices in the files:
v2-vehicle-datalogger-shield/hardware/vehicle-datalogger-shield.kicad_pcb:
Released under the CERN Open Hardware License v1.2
